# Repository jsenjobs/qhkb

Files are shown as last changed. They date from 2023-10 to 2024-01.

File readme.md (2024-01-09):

# qh-ws42-v2

    42键无线分体，主控nrf52840

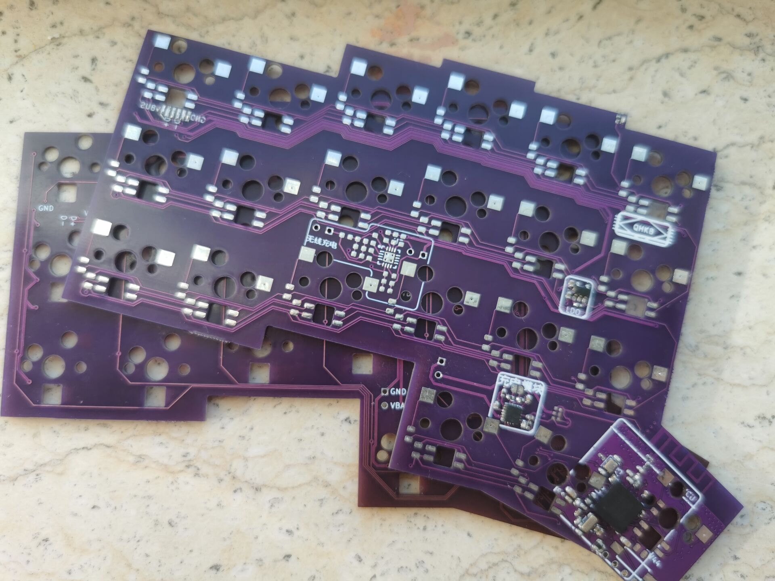
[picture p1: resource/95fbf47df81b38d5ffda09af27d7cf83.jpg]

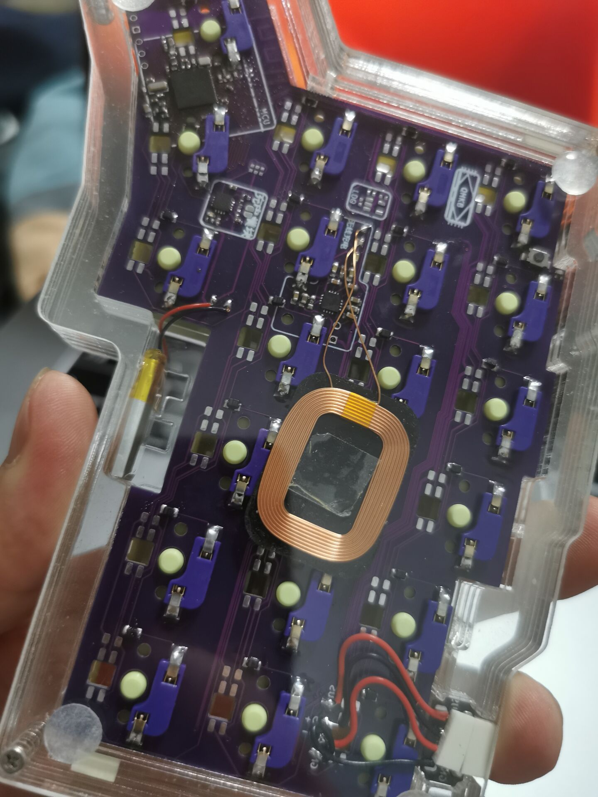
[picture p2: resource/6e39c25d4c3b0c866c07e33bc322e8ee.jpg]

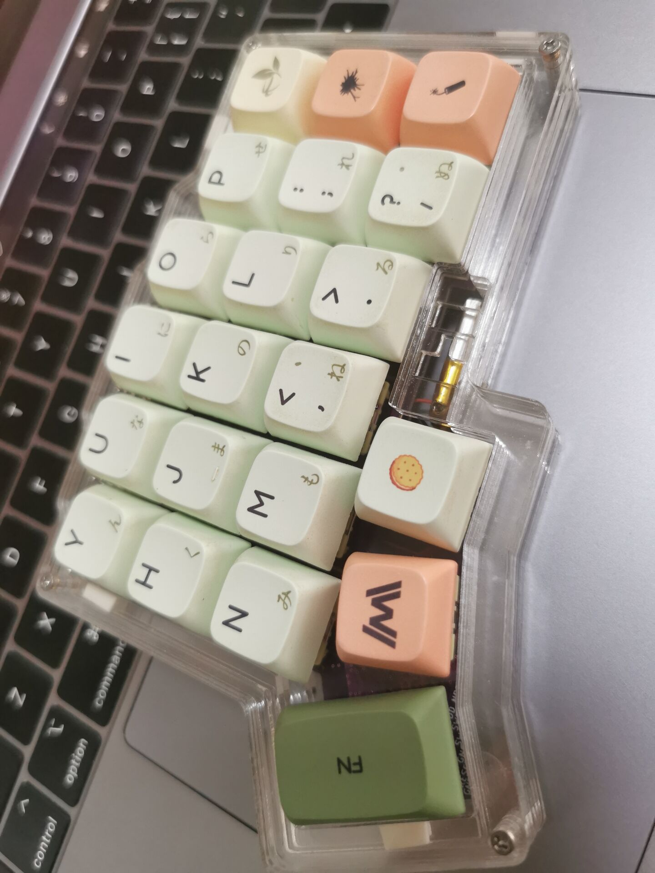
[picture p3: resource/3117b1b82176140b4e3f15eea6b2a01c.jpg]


# qh-s42-v5

    42键有线小红点分体，主控apm32f103cbt6，兼容3x5配列，还没测过。
    固件部分源码在 vial-qmk 下。

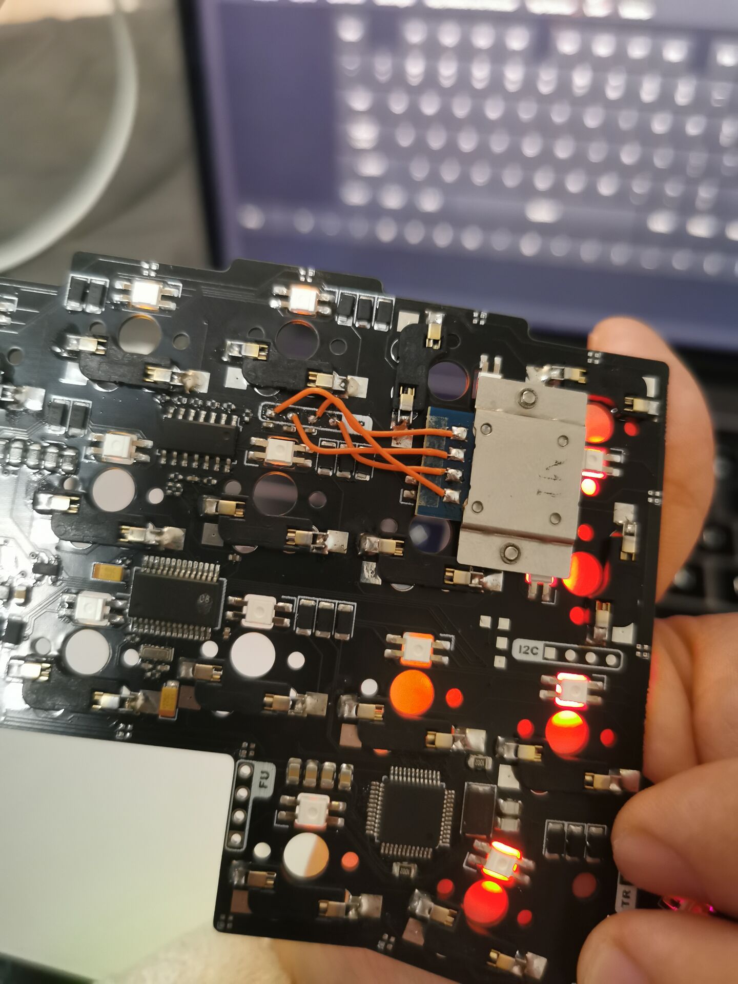
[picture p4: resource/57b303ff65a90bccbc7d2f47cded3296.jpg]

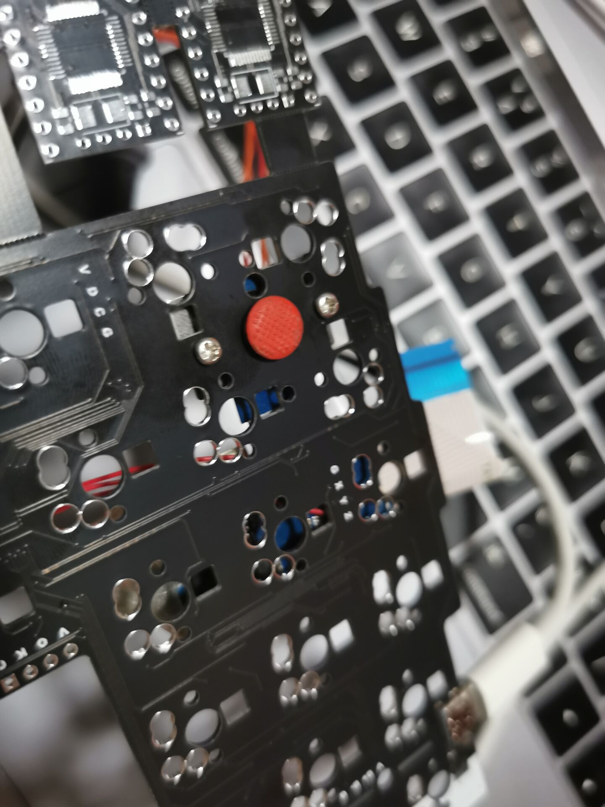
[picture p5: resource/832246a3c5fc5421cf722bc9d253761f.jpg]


# --

    如果有自己设计好的键盘外壳，联系我，分享一下。

    交流咨询可以咸鱼搜qhkb。
    QQ：1922279340

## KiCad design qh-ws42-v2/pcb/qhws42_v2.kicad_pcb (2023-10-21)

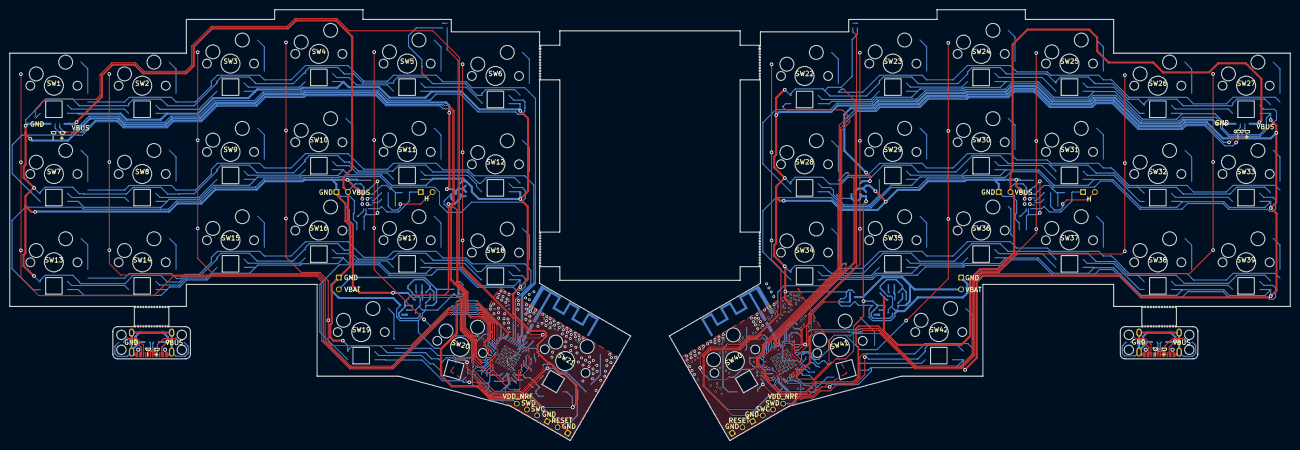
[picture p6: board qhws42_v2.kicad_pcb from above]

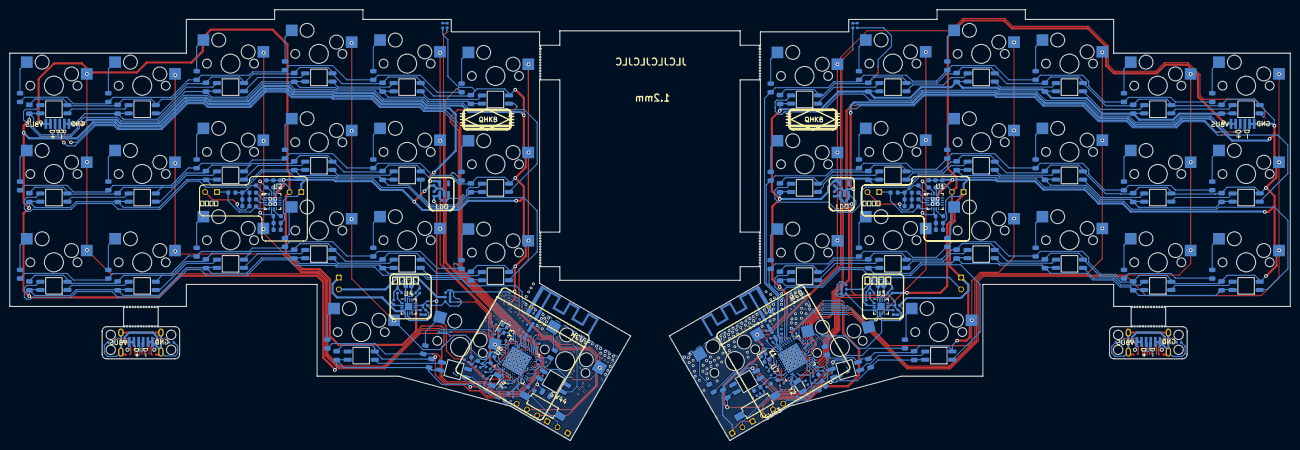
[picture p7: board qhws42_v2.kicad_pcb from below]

Board: 2 copper layers, 276.2 x 92.9 mm, 316 parts (272 on the bottom side), 204 nets.

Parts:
AE1: Antenna_Shield; ANT_LEFT
AE2: Antenna_Shield; ANT_RIGHT
C1, C2, C3, C4, C5, C6, C7, C8, C9, C10, C11, C12, C13, C14, C15, C16, C17, C18, C19, C20, C21, C22, C23, C24, C25, C26, C27, C28, C29, C30, C31, C32, C33, C34, C35, C36, C37, C38, C39, C40, C41, C42: C; C_0805_2012Metric
C43, C50, C54, C63: 100nF; C_0603_1608Metric
C44, C46, C47, C55, C58, C59: 47nF; C_0603_1608Metric
C45, C56: 33nF; C_0603_1608Metric
C48, C57: 2.2nF; C_0603_1608Metric
C49, C51, C52, C60, C61, C62: 10uF; C_0603_1608Metric
C53, C64, C94, C116: 1uF; C_0603_1608Metric
C65, C68, C85, C107: 1uF; C_0402_1005Metric
C66, C67, C69, C70, C72, C75, C77, C91, C92, C99, C113, C114: 4.7uF; C_0402_1005Metric
C71, C74: 10uF; C_0402_1005Metric
C73, C76, C78, C80, C81, C87, C100, C102, C103, C109: 100nF; C_0402_1005Metric
C79, C88, C96, C101, C110, C118: N.C.; C_0402_1005Metric
C82, C86, C104, C108: 1pF; C_0402_1005Metric
C83, C84, C97, C98, C105, C106, C119, C120: 12pF; C_0402_1005Metric
C89, C111: 100pF; C_0402_1005Metric
C90, C112: 820pF; C_0402_1005Metric
C93, C115: 4.7uF; C_0603_1608Metric
C95, C117: 47nF; C_0402_1005Metric
D1, D2, D3, D4, D5, D6, D7, D8, D9, D10, D11, D12, D13, D14, D15, D16, D17, D18, D19, D20, D21, D22, D23, D24, D25, D26, D27, D28, D29, D30, D31, D32, D33, D34, D35, D36, D37, D38, D39, D40, D41, D42: D; D_0805_2012Metric
D43, D44: RED; LED_0402_1005Metric
D45, D46: BLUE; LED_0402_1005Metric
FFC1, FFC2, FFC3, FFC4: fpc_1mm_6pin; fpc_1mm_6pin_thin
J1, J3: 15.8uH; connector_2pin
J2, J4: VOUT; connector_2pin
J5, J7: Conn_01x04; connector_swd
J6, J8, J9, J10: Conn_01x02; connector_2pin
JP1, JP2: Boost; SolderJumper-2_P1.3mm_Open_RoundedPad1.0x1.5mm
L1, L5: 3.9nH; L_0402_1005Metric
L2, L6: 15nH; L_0402_1005Metric
L3, L4, L7, L8: 10uH; L_0603_1608Metric
LED1, LED2, LED3, LED4, LED5, LED6, LED7, LED8, LED9, LED10, LED11, LED12, LED13, LED14, LED15, LED16, LED17, LED18, LED19, LED20, LED21, LED22, LED23, LED24, LED25, LED26, LED27, LED28, LED29, LED30, LED31, LED32, LED33, LED34, LED35, LED36, LED37, LED38, LED39, LED40, LED41, LED42: rgb_4pin; rgb_3528
R1, R2: 220R; R_0603_1608Metric
R3, R7: 2k; R_0402_1005Metric
R4, R5, R6, R8, R9, R10: 10k; R_0402_1005Metric
R11, R14: 10M; R_0402_1005Metric
R12, R15: 820k; R_0402_1005Metric
R13, R16: 2M; R_0402_1005Metric
R17, R19: 0r; R_0402_1005Metric
R18, R20: 1k; R_0402_1005Metric
R21, R22, R23, R24: 5.1k; R_0402_1005Metric
SW1, SW2, SW3, SW4, SW5, SW6, SW7, SW8, SW9, SW10, SW11, SW12, SW13, SW14, SW15, SW16, SW17, SW18, SW19, SW20, SW21, SW22, SW23, SW24, SW25, SW26, SW27, SW28, SW29, SW30, SW31, SW32, SW33, SW34, SW35, SW36, SW37, SW38, SW39, SW40, SW41, SW42: sw_qhkb; switch_hotswap_1u
SW43, SW44: Reed_GPS-11A-SMD; Reed_SW-RI-80SMD-1015-G2
U1, U2: KICAD_NU1680; KICAD_QFN-16_L3.0-W3.0-P0.50-TL-EP1.9
U3, U4: BQ24075RGT; VQFN-16-1EP_3x3mm_P0.5mm_EP1.6x1.6mm
U5, U6: XC6220B331MR; SOT-23-5
U7, U8: nRF52840; Nordic_AQFN-73-1EP_7x7mm_P0.5mm
USB1, USB2: TYPE-C_16PIN_2MD(073); USB-C-SMD_TYPE-C-6PIN-2MD-073
Y1, Y3: 32MHz; Crystal_SMD_2016-4Pin_2.0x1.6mm
Y2, Y4: 32.768kHz; Crystal_SMD_3215-2Pin_3.2x1.5mm

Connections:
/D+_TC_l: FFC3.4, USB1.6 (DP1), USB1.8 (DP2)
/D+_TC_r: FFC4.4, USB2.6 (DP1), USB2.8 (DP2)
/D-_TC_l: FFC3.3, USB1.5 (DN2), USB1.7 (DN1)
/D-_TC_r: FFC4.3, USB2.5 (DN2), USB2.7 (DN1)
/GND_TC_l: FFC3.1, FFC3.2, R21.2, R22.2, USB1.1 (GND), USB1.12 (GND), USB1.13 (SHELL), USB1.14 (SHELL)
/GND_TC_r: FFC4.1, FFC4.2, R23.2, R24.2, USB2.1 (GND), USB2.12 (GND), USB2.13 (SHELL), USB2.14 (SHELL)
/VBUS_TC_l: FFC3.5, FFC3.6, USB1.2 (VBUS), USB1.11 (VBUS)
/VBUS_TC_r: FFC4.5, FFC4.6, USB2.2 (VBUS), USB2.11 (VBUS)
/VRECT_l: C49.2, C50.2, C51.2, R1.1, U1.6 (VRECT), U1.15 (VRECT)
/VRECT_r: C61.2, C62.2, C63.2, R2.1, U2.6 (VRECT), U2.15 (VRECT)
ANTENNA_l: AE1.1 (A), C79.2, R17.1
ANTENNA_r: AE2.1 (A), C101.2, R19.1
BATTERY_LEVEL_PIN_l: C73.2, R12.1, R13.2, U7.J1 (AIN2/P0.04)
BATTERY_LEVEL_PIN_r: C76.2, R15.1, R16.2, U8.J1 (AIN2/P0.04)
BLED_l: D45.2 (A), U7.AD10 (P0.15)
BLED_r: D46.2 (A), U8.A16 (P1.13)
COL0_l: SW1.1, SW7.1, SW13.1, U7.AD12 (P0.17)
COL0_r: SW22.1, SW28.1, SW34.1, SW40.1, U8.AD12 (P0.17)
COL1_l: SW2.1, SW8.1, SW14.1, U7.AD16 (P0.20)
COL1_r: SW23.1, SW29.1, SW35.1, SW41.1, U8.A20 (P1.10)
COL2_l: SW3.1, SW9.1, SW15.1, U7.AD18 (P0.22)
COL2_r: SW24.1, SW30.1, SW36.1, SW42.1, U8.A14 (P1.15)
COL3_l: SW4.1, SW10.1, SW16.1, SW19.1, U7.AD20 (P0.24)
COL3_r: SW25.1, SW31.1, SW37.1, U8.A12 (AIN0/P0.02)
COL4_l: SW5.1, SW11.1, SW17.1, SW20.1, U7.AD22 (TRACEDATA0/P1.00)
COL4_r: SW26.1, SW32.1, SW38.1, U8.L1 (P0.06)
COL5_l: SW6.1, SW12.1, SW18.1, SW21.1, U7.W24 (P1.02)
COL5_r: SW27.1, SW33.1, SW39.1, U8.N1 (P0.08)
D+_l: FFC1.3, U7.AD6 (D+)
D+_r: FFC2.3, U8.AD6 (D+)
D-_l: FFC1.4, U7.AD4 (D-)
D-_r: FFC2.4, U8.AD4 (D-)
EXT_VCC_l: C1.2, C2.2, C3.2, C4.2, C5.2, C6.2, C7.2, C8.2, C9.2, C10.2, C11.2, C12.2, C13.2, C14.2, C15.2, C16.2, C17.2, C18.2, C19.2, C20.2, C21.2, C72.2, LED1.1 (VDD), LED2.1 (VDD), LED3.1 (VDD), LED4.1 (VDD), LED5.1 (VDD), LED6.1 (VDD), LED7.1 (VDD), LED8.1 (VDD), LED9.1 (VDD), LED10.1 (VDD), LED11.1 (VDD), LED12.1 (VDD), LED13.1 (VDD), LED14.1 (VDD), LED15.1 (VDD), LED16.1 (VDD), LED17.1 (VDD), LED18.1 (VDD), LED19.1 (VDD), LED20.1 (VDD), LED21.1 (VDD), U5.5 (VOUT)
EXT_VCC_r: C22.2, C23.2, C24.2, C25.2, C26.2, C27.2, C28.2, C29.2, C30.2, C31.2, C32.2, C33.2, C34.2, C35.2, C36.2, C37.2, C38.2, C39.2, C40.2, C41.2, C42.2, C75.2, LED22.1 (VDD), LED23.1 (VDD), LED24.1 (VDD), LED25.1 (VDD), LED26.1 (VDD), LED27.1 (VDD), LED28.1 (VDD), LED29.1 (VDD), LED30.1 (VDD), LED31.1 (VDD), LED32.1 (VDD), LED33.1 (VDD), LED34.1 (VDD), LED35.1 (VDD), LED36.1 (VDD), LED37.1 (VDD), LED38.1 (VDD), LED39.1 (VDD), LED40.1 (VDD), LED41.1 (VDD), LED42.1 (VDD), U6.5 (VOUT)
GND_l: AE1.2 (Shield), C1.1, C2.1, C3.1, C4.1, C5.1, C6.1, C7.1, C8.1, C9.1, C10.1, C11.1, C12.1, C13.1, C14.1, C15.1, C16.1, C17.1, C18.1, C19.1, C20.1, C21.1, C49.1, C50.1, C51.1, C52.2, C53.1, C65.1, C66.1, C67.1, C71.1, C72.1, C73.1, C77.1, C78.1, C79.1, C80.1, C81.1, C82.1, C83.1, C84.2, C85.1, C86.1, C87.1, C88.1, C89.1, C90.2, C91.1, C92.2, C93.2, C94.2, C95.2, C96.2, C97.2, C98.2, FFC1.5, FFC1.6, J2.1, J5.1, J6.1, J9.1, LED1.3 (VSS), LED2.3 (VSS), LED3.3 (VSS), LED4.3 (VSS), LED5.3 (VSS), LED6.3 (VSS), LED7.3 (VSS), LED8.3 (VSS), LED9.3 (VSS), LED10.3 (VSS), LED11.3 (VSS), LED12.3 (VSS), LED13.3 (VSS), LED14.3 (VSS), LED15.3 (VSS), LED16.3 (VSS), LED17.3 (VSS), LED18.3 (VSS), LED19.3 (VSS), LED20.3 (VSS), LED21.3 (VSS), R3.2, R4.1, R5.2, R13.1, R18.2, SW43.2, U1.1 (GND), U1.4 (GND), U1.17 (EP), U3.4 (~CE), U3.5 (EN2), U3.8 (VSS), U3.15 (SYSOFF), U3.17 (VSS), U5.2 (GND), U7.B7 (VSS), U7.EP (VSS), U7.F23 (VSS_PA), Y1.2, Y1.4
GND_r: AE2.2 (Shield), C22.1, C23.1, C24.1, C25.1, C26.1, C27.1, C28.1, C29.1, C30.1, C31.1, C32.1, C33.1, C34.1, C35.1, C36.1, C37.1, C38.1, C39.1, C40.1, C41.1, C42.1, C60.2, C61.1, C62.1, C63.1, C64.1, C68.1, C69.1, C70.1, C74.1, C75.1, C76.1, C99.1, C100.1, C101.1, C102.1, C103.1, C104.1, C105.1, C106.2, C107.1, C108.1, C109.1, C110.1, C111.1, C112.2, C113.1, C114.2, C115.2, C116.2, C117.2, C118.2, C119.2, C120.2, FFC2.5, FFC2.6, J4.1, J7.1, J8.1, J10.1, LED22.3 (VSS), LED23.3 (VSS), LED24.3 (VSS), LED25.3 (VSS), LED26.3 (VSS), LED27.3 (VSS), LED28.3 (VSS), LED29.3 (VSS), LED30.3 (VSS), LED31.3 (VSS), LED32.3 (VSS), LED33.3 (VSS), LED34.3 (VSS), LED35.3 (VSS), LED36.3 (VSS), LED37.3 (VSS), LED38.3 (VSS), LED39.3 (VSS), LED40.3 (VSS), LED41.3 (VSS), LED42.3 (VSS), R7.2, R8.1, R9.2, R16.1, R20.2, SW44.2, U2.1 (GND), U2.4 (GND), U2.17 (EP), U4.4 (~CE), U4.5 (EN2), U4.8 (VSS), U4.15 (SYSOFF), U4.17 (VSS), U6.2 (GND), U8.B7 (VSS), U8.EP (VSS), U8.F23 (VSS_PA), Y3.2, Y3.4
unnamed: C82.2, L1.1, R17.2
unnamed: C104.2, L5.1, R19.2
unnamed: D1.2 (A), SW1.2
unnamed: D2.2 (A), SW2.2
unnamed: D3.2 (A), SW3.2
unnamed: D4.2 (A), SW4.2
unnamed: D5.2 (A), SW5.2
unnamed: D6.2 (A), SW6.2
unnamed: D7.2 (A), SW7.2
unnamed: D8.2 (A), SW8.2
unnamed: D9.2 (A), SW9.2
unnamed: D10.2 (A), SW10.2
unnamed: D11.2 (A), SW11.2
unnamed: D12.2 (A), SW12.2
unnamed: D13.2 (A), SW13.2
unnamed: D14.2 (A), SW14.2
unnamed: D15.2 (A), SW15.2
unnamed: D16.2 (A), SW16.2
unnamed: D17.2 (A), SW17.2
unnamed: D18.2 (A), SW18.2
unnamed: D19.2 (A), SW19.2
unnamed: D20.2 (A), SW20.2
unnamed: D21.2 (A), SW21.2
unnamed: D22.2 (A), SW22.2
unnamed: D23.2 (A), SW23.2
unnamed: D24.2 (A), SW24.2
unnamed: D25.2 (A), SW25.2
unnamed: D26.2 (A), SW26.2
unnamed: D27.2 (A), SW27.2
unnamed: D28.2 (A), SW28.2
unnamed: D29.2 (A), SW29.2
unnamed: D30.2 (A), SW30.2
unnamed: D31.2 (A), SW31.2
unnamed: D32.2 (A), SW32.2
unnamed: D33.2 (A), SW33.2
unnamed: D34.2 (A), SW34.2
unnamed: D35.2 (A), SW35.2
unnamed: D36.2 (A), SW36.2
unnamed: D37.2 (A), SW37.2
unnamed: D38.2 (A), SW38.2
unnamed: D39.2 (A), SW39.2
unnamed: D40.2 (A), SW40.2
unnamed: D41.2 (A), SW41.2
unnamed: D42.2 (A), SW42.2
unnamed: D43.2 (A), R6.1
unnamed: D43.1 (K), U3.9 (~CHG)
unnamed: D44.2 (A), R10.1
unnamed: D44.1 (K), U4.9 (~CHG)
unnamed: D45.1 (K), R18.1
unnamed: D46.1 (K), R20.1
unnamed: C47.1, C48.1, J1.1, U1.5 (AC2)
unnamed: C43.1, C44.1, C45.1, J1.2
unnamed: C57.1, C59.1, J3.1, U2.5 (AC2)
unnamed: C54.1, C55.1, C56.1, J3.2
unnamed: JP1.2, R3.1
unnamed: JP2.2, R7.1
unnamed: L2.2, L3.1
unnamed: L6.2, L7.1
unnamed: LED1.2 (DOUT), LED2.4 (DIN)
unnamed: LED2.2 (DOUT), LED3.4 (DIN)
unnamed: LED3.2 (DOUT), LED4.4 (DIN)
unnamed: LED4.2 (DOUT), LED5.4 (DIN)
unnamed: LED5.2 (DOUT), LED6.4 (DIN)
unnamed: LED6.2 (DOUT), LED7.4 (DIN)
unnamed: LED7.2 (DOUT), LED8.4 (DIN)
unnamed: LED8.2 (DOUT), LED9.4 (DIN)
unnamed: LED9.2 (DOUT), LED10.4 (DIN)
unnamed: LED10.2 (DOUT), LED11.4 (DIN)
unnamed: LED11.2 (DOUT), LED12.4 (DIN)
unnamed: LED12.2 (DOUT), LED13.4 (DIN)
unnamed: LED13.2 (DOUT), LED14.4 (DIN)
unnamed: LED14.2 (DOUT), LED15.4 (DIN)
unnamed: LED15.2 (DOUT), LED16.4 (DIN)
unnamed: LED16.2 (DOUT), LED17.4 (DIN)
unnamed: LED17.2 (DOUT), LED18.4 (DIN)
unnamed: LED18.2 (DOUT), LED19.4 (DIN)
unnamed: LED19.2 (DOUT), LED20.4 (DIN)
unnamed: LED20.2 (DOUT), LED21.4 (DIN)
unnamed: LED22.2 (DOUT), LED23.4 (DIN)
unnamed: LED23.2 (DOUT), LED24.4 (DIN)
unnamed: LED24.2 (DOUT), LED25.4 (DIN)
unnamed: LED25.2 (DOUT), LED26.4 (DIN)
unnamed: LED26.2 (DOUT), LED27.4 (DIN)
unnamed: LED27.2 (DOUT), LED28.4 (DIN)
unnamed: LED28.2 (DOUT), LED29.4 (DIN)
unnamed: LED29.2 (DOUT), LED30.4 (DIN)
unnamed: LED30.2 (DOUT), LED31.4 (DIN)
unnamed: LED31.2 (DOUT), LED32.4 (DIN)
unnamed: LED32.2 (DOUT), LED33.4 (DIN)
unnamed: LED33.2 (DOUT), LED34.4 (DIN)
unnamed: LED34.2 (DOUT), LED35.4 (DIN)
unnamed: LED35.2 (DOUT), LED36.4 (DIN)
unnamed: LED36.2 (DOUT), LED37.4 (DIN)
unnamed: LED37.2 (DOUT), LED38.4 (DIN)
unnamed: LED38.2 (DOUT), LED39.4 (DIN)
unnamed: LED39.2 (DOUT), LED40.4 (DIN)
unnamed: LED40.2 (DOUT), LED41.4 (DIN)
unnamed: LED41.2 (DOUT), LED42.4 (DIN)
unnamed: C43.2, C44.2, C45.2, C46.2, C48.2, U1.16 (AC1)
unnamed: C46.1, U1.2 (COMM1)
unnamed: C47.2, U1.3 (COMM2)
unnamed: R1.2, U1.7 (SINK)
unnamed: C53.2, U1.13 (V5V)
unnamed: C54.2, C55.2, C56.2, C57.2, C58.2, U2.16 (AC1)
unnamed: C58.1, U2.2 (COMM1)
unnamed: C59.2, U2.3 (COMM2)
unnamed: R2.2, U2.7 (SINK)
unnamed: C64.2, U2.13 (V5V)
unnamed: JP1.1, R4.2, U3.16 (ISET)
unnamed: R5.1, U3.1 (TS)
unnamed: JP2.1, R8.2, U4.16 (ISET)
unnamed: R9.1, U4.1 (TS)
unnamed: C86.2, L1.2, U7.H23 (ANT)
unnamed: L3.2, U7.B3 (DCC)
unnamed: L4.1, U7.AB2 (DCCH)
unnamed: C87.2, U7.C1 (DEC1)
unnamed: C88.2, U7.A18 (DEC2)
unnamed: C89.2, U7.D23 (DEC3)
unnamed: C94.1, C95.1, C96.1, L2.1, U7.B5 (DEC4), U7.E24 (DEC6)
unnamed: C90.1, U7.N24 (DEC5)
unnamed: C91.2, U7.AC5 (DECUSB)
unnamed: C83.2, U7.B24 (XC1), Y1.1
unnamed: C84.1, U7.A23 (XC2), Y1.3
unnamed: C97.1, U7.D2 (XL1/P0.00), Y2.2
unnamed: C98.1, U7.F2 (XL2/P0.01), Y2.1
unnamed: C108.2, L5.2, U8.H23 (ANT)
unnamed: L7.2, U8.B3 (DCC)
unnamed: L8.1, U8.AB2 (DCCH)
unnamed: C109.2, U8.C1 (DEC1)
unnamed: C110.2, U8.A18 (DEC2)
unnamed: C111.2, U8.D23 (DEC3)
unnamed: C116.1, C117.1, C118.1, L6.1, U8.B5 (DEC4), U8.E24 (DEC6)
unnamed: C112.1, U8.N24 (DEC5)
unnamed: C113.2, U8.AC5 (DECUSB)
unnamed: C105.2, U8.B24 (XC1), Y3.1
unnamed: C106.1, U8.A23 (XC2), Y3.3
unnamed: C119.1, U8.D2 (XL1/P0.00), Y4.2
unnamed: C120.1, U8.F2 (XL2/P0.01), Y4.1
unnamed: R22.1, USB1.4 (CC1)
unnamed: R21.1, USB1.10 (CC2)
unnamed: R24.1, USB2.4 (CC1)
unnamed: R23.1, USB2.10 (CC2)
POWER_PIN_l: R11.2, U5.3 (CE), U7.AD8 (P0.13)
POWER_PIN_r: R14.2, U6.3 (CE), U8.AD8 (P0.13)
RESET_l: J6.2, SW43.1, U7.AC9 (P0.14), U7.AC11 (P0.16), U7.AC13 (P0.18/~RESET)
RESET_r: J8.2, SW44.1, U8.AC9 (P0.14), U8.AC11 (P0.16), U8.AC13 (P0.18/~RESET)
RGB_l: LED1.4 (DIN), U7.U24 (P1.04)
RGB_r: LED22.4 (DIN), U8.W24 (P1.02)
ROW0_l: D1.1 (K), D2.1 (K), D3.1 (K), D4.1 (K), D5.1 (K), D6.1 (K), U7.J24 (NFC2/P0.10)
ROW0_r: D22.1 (K), D23.1 (K), D24.1 (K), D25.1 (K), D26.1 (K), D27.1 (K), U8.U24 (P1.04)
ROW1_l: D7.1 (K), D8.1 (K), D9.1 (K), D10.1 (K), D11.1 (K), D12.1 (K), U7.L24 (NFC1/P0.09)
ROW1_r: D28.1 (K), D29.1 (K), D30.1 (K), D31.1 (K), D32.1 (K), D33.1 (K), U8.L24 (NFC1/P0.09)
ROW2_l: D13.1 (K), D14.1 (K), D15.1 (K), D16.1 (K), D17.1 (K), D18.1 (K), U7.R24 (P1.06)
ROW2_r: D34.1 (K), D35.1 (K), D36.1 (K), D37.1 (K), D38.1 (K), D39.1 (K), U8.J24 (NFC2/P0.10)
ROW3_l: D19.1 (K), D20.1 (K), D21.1 (K), U7.A14 (P1.15)
ROW3_r: D40.1 (K), D41.1 (K), D42.1 (K), U8.AD20 (P0.24)
SWC_l: J5.2, U7.AA24 (SWDCLK)
SWC_r: J7.2, U8.AA24 (SWDCLK)
SWD_l: J5.3, U7.AC24 (SWDIO)
SWD_r: J7.3, U8.AC24 (SWDIO)
VBAT_l: C67.2, J9.2, R12.2, U3.2 (BAT), U3.3 (BAT)
VBAT_r: C70.2, J10.2, R15.2, U4.2 (BAT), U4.3 (BAT)
VBUS_l: C52.1, C65.2, C93.1, FFC1.1, FFC1.2, J2.2, U1.14 (VOUT), U3.13 (IN), U7.AD2 (VBUS)
VBUS_r: C60.1, C68.2, C115.1, FFC2.1, FFC2.2, J4.2, U2.14 (VOUT), U4.13 (IN), U8.AD2 (VBUS)
VDDH_l: C66.2, C71.2, C92.1, R6.2, R11.1, U3.6 (EN1), U3.10 (OUT), U3.11 (OUT), U5.1 (VIN), U7.Y2 (VDDH)
VDDH_r: C69.2, C74.2, C114.1, R10.2, R14.1, U4.6 (EN1), U4.10 (OUT), U4.11 (OUT), U6.1 (VIN), U8.Y2 (VDDH)
VDD_NRF_l: C77.2, C78.2, C80.2, C81.2, C85.2, J5.4, L4.2, U7.A22 (VDD), U7.AD14 (VDD), U7.AD23 (VDD), U7.B1 (VDD), U7.W1 (VDD)
VDD_NRF_r: C99.2, C100.2, C102.2, C103.2, C107.2, J7.4, L8.2, U8.A22 (VDD), U8.AD14 (VDD), U8.AD23 (VDD), U8.B1 (VDD), U8.W1 (VDD)
